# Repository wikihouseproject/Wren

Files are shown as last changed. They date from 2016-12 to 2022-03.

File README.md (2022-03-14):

### IMPORTANT: This is now an outdated, unsupported WikiHouse system. For the latest WikiHouse core system info please see the [Skylark repo](https://github.com/wikihouseproject/Skylark) and [WikiHouse guides](https://www.wikihouse.cc/guides)

# Wren

The language and rules for the Wren Wikihouse structural system, suitable for 1-3 storey buildings and initially developed in the UK for European contexts.

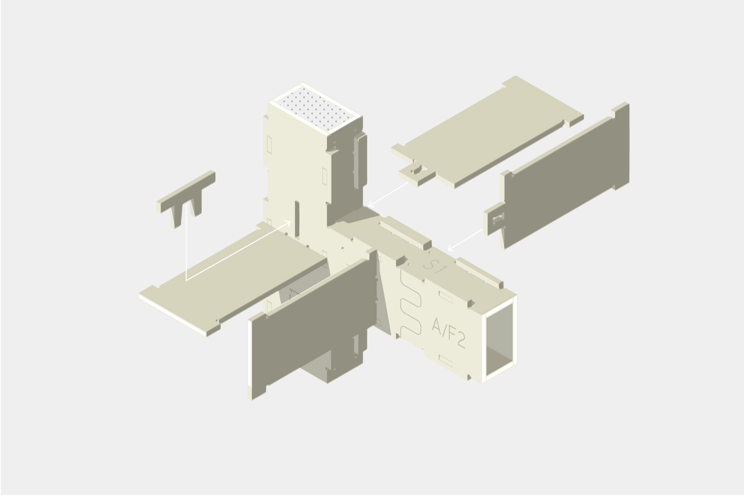
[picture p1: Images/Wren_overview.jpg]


## Wren Hardware

Wren components are CNC manufuctured using structural-grade timber panel materials (typically, plywood) and can be rapidly assembled to produce a structural chassis, onto which other components such as cladding, windows, doors can be fitted.

#### Wren is in development. For full documentation on how Wren works and how you can contribute to its development, visit the [Wren wiki](https://github.com/wikihouseproject/Wren/wiki)

## Wren Parametrics

This version of the Wren structural language has been developed in Grasshopper, the parametric scripting plugin for Rhino 3D. This computational design platform is widely used in the design and construction industries, and is ideally suited to digital manufacturing.

Other formats of the Wren system are currently being developed, but currently this version in Grasshopper format represents the latest thinking and workflow for the structural technology.

It should be taken as a Work in Progress and follows ‘a build something that works first’ approach. There are still several known areas where efficiency can be improved. There are also many ways the script can be extended to make use of Grasshopper’s expansive suite of tools include new features like structural analysis, nesting, GIS data, and solar/environmental tracking. We gladly welcome contributions from fellow computational designers to fork and develop!

### Licence

The repository Grasshopper file WikiHouse_WREN_(v4.3) has been developed by Architecture 00.  

It is licensed under Mozilla Public Licence (MPL) version 2.0. For full legal terms of this licence visit: https://www.mozilla.org/en-US/MPL/2.0/

### Plugins

This script makes use of the excellent developers toolbox of Grasshopper plugins, which makes this all possible. You will need to download and install the latest versions of these plugins from Food4Rhino.com before opening and running this script file.

The plugins used are:

- [Leafcutter](http://www.food4rhino.com/app/leafcutter-google-sheets-grasshopper) - for google sheets integration
- [Elefront](http://www.food4rhino.com/app/elefront) - for automated Grasshopper-to-Rhino flow
- [Human](http://www.food4rhino.com/app/human) - for automated Grasshopper-to-Rhino flow
- [Metahopper](http://www.grasshopper3d.com/group/metahopper) - for batch exports and script analysis

### Known issues / limits

- **D-Joint splitting of the frame** - there is currently a very basic version of the logic but this probably needs to be custom scripted. The basic rules are no section should be larger than the sheet material (nominally 1220 x 2440mm) and D-joints are never closer than two grips to any corner/junction
- **Integration with Google Sheets** - While you can ‘drive’ the Wren script using the parameter sliders, the best way makes use of the Leafcutter plugin, which connects the script with a google spreadsheet for the input and output of project data. This is particularly handy when setting out the window and door sizes and locations.
- **Number of roof points** - Here be bugs, it may not work for multiple roof points and may also break the frame/sheathing geometry. Use with care.
- **Tolerance** - While tolerances can be added to slots in the 3D model, a much better/safer approach is to add tolerance offsets to the final nested cutting files, and keep the 3D geometry at 0mm tolerance.
- **Data Tree structures** - These can be streamlined much further within the Sheathing and Spacer component clusters to improve the file size/solution speed
- Custom scripts - custom C# / Python scripts can and should be added to replace large sections of the script to improve the flow and speed up processing
- **End-walls (in development)** - The gable end walls use the Wikihouse Weaver system (cassette-based) and still more development needed on an automated workflow here, specifically with how the front and rear facades are divided up around window openings. The parametric script for Weaver is not yet included in this initial release.
- **Notes/comments** -  There’s a definite lack of these in the clusters and subclusters. More detail and comments will be added soon, my apologies! If you have particularly questions get in touch via email or raise an issue here.

## Wren Hardware R&D Contributions

**Architecture 00** (www.architecture00.net)
- [Alastair Parvin](https://twitter.com/AlastairParvin)
- [David Saxby](https://twitter.com/davidsx00)
- [Ryan McLoughlin](https://twitter.com/ryanjamesmac)
- [Clayton Prest](https://twitter.com/ClaytonPrest) 
- [Nick Ierodiaconou](https://twitter.com/nick_diaconou) 
- [Joni Steiner](https://twitter.com/jonisteiner)

**Momentum Engineering** (www.momentumengineering.com)
- Ben Whitfield
- Steve Fisher
- Rosie Stevenson

**Space Craft Systems** (www.spacecraft.co.nz)
- [Danny Squires](https://twitter.com/ecoarknz)
- [Martin Luff](https://twitter.com/martinluff)

**Arup Associates** (www.arup.com)
- Nina Tabink
- Adrian Campbell

**Individual Contributors**
- [Alex Whitcroft](https://twitter.com/AlexWhitcroft)
- Justyna Swat
- Nico Maes
- Akiko Kobayashi

**ULB Bruxelles**
- Structural engineering student group

## Wren Parametric Contributions

**Architecture 00** (www.architecture00.net)
- [Clayton Prest](https://twitter.com/ClaytonPrest) 

**Architype - Team Architects** (http://www.architype-ta.co.nz/)
- [Agneesh Brahmbhatt](https://www.linkedin.com/in/agneesh-brahmbhatt-7557234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)

If you believe you are missing from either of these lists of historical contributions, please contact us or fork this document to amend.

# Terms of use

By downloading these files or information you agree to the following terms and conditions.

Information is shared without any kind of warranty or guarantee
All Information is provided ‘as is’. No representations or warranties express or implied are made regarding the Wikihouse Info, its accuracy, completeness, functionality or fitness for a particular use in a particular location.  

You are solely responsible for the use of the information
By using this information you assume full responsibility for any loss resulting from use or inability to use the Wikihouse Info, and forever releases WikiHouse Foundation or other WikiHouse users from any liability for such loss;  including but not limited to loss of profits, goodwill or assets.

You are responsible for meeting local codes and legislation
Users must satisfy themselves regarding the application of statutory requirements, local building regulations, codes, insurance certification or other requirements or recommendations relevant to the location where and materials with which they plan to build. Where required you should always seek the advice of a relevant qualified professional.

You are responsible for using the information in a safe way
 Users are responsible for ensuring that information they use or cause to be used is used in a way which is safe, and is not likely to cause harm during or after manufacturing, construction, use or disassembly.

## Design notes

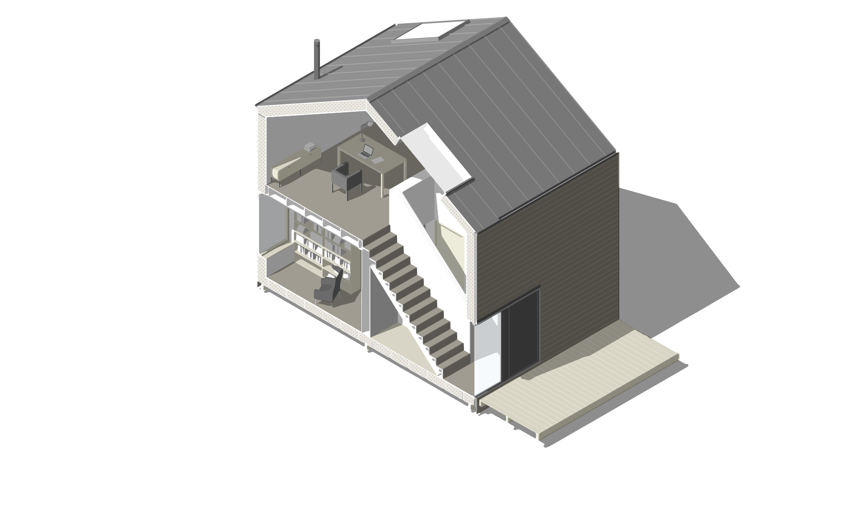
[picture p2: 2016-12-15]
Images/Process_8.jpg

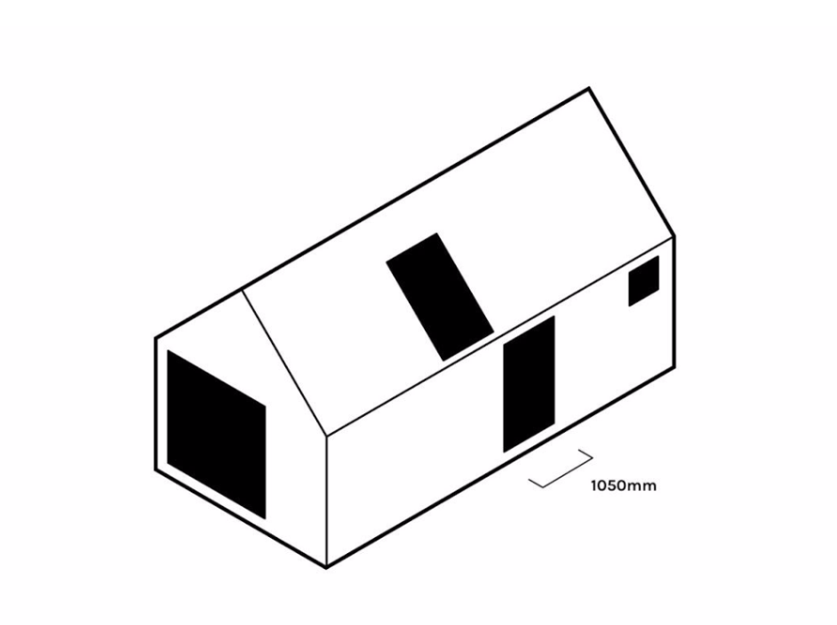
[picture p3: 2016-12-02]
Images/Openings-01.png

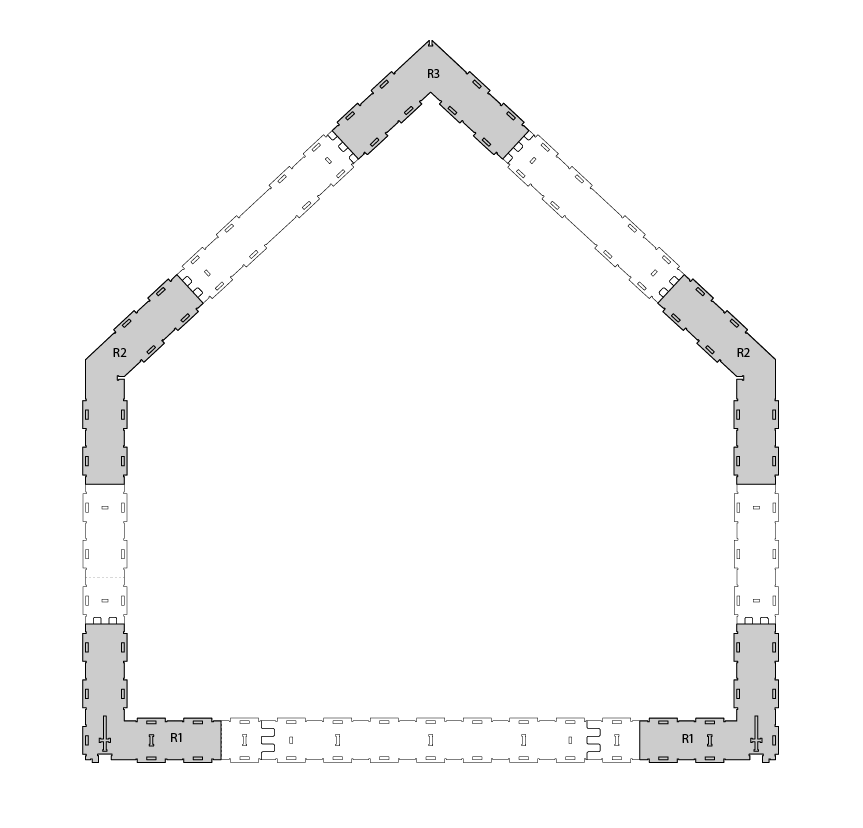
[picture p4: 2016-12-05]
Images/Reinforcer-01.png

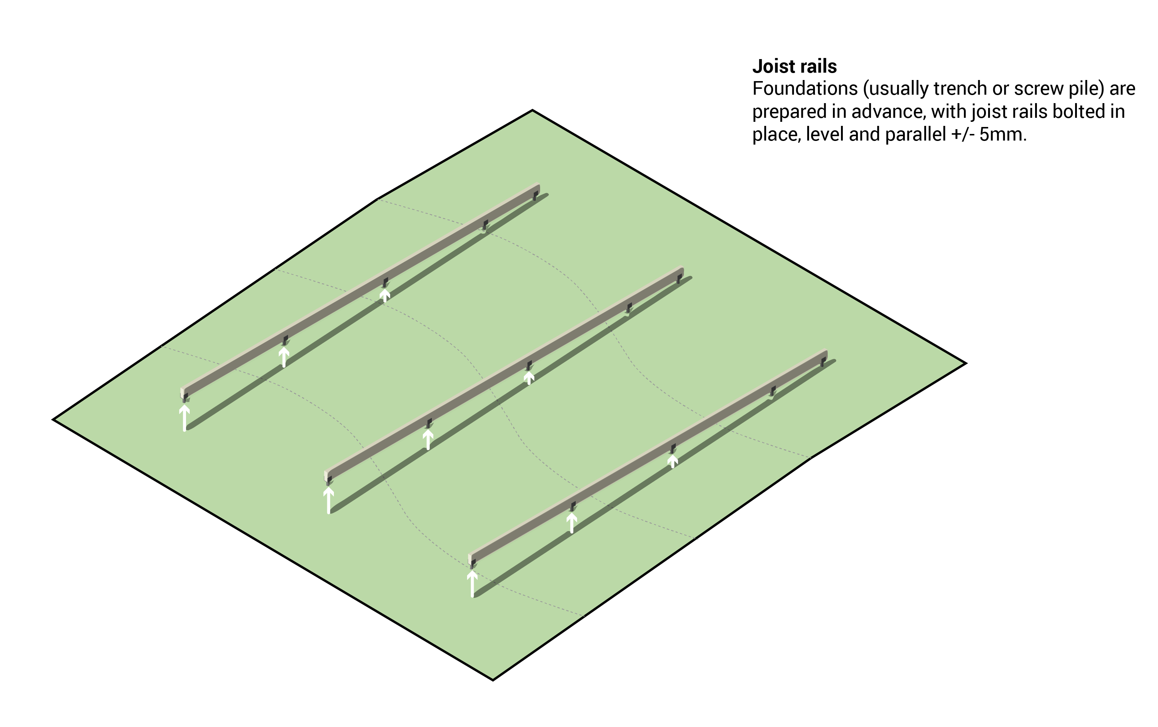
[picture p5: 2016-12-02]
Images/Foundation-01.png

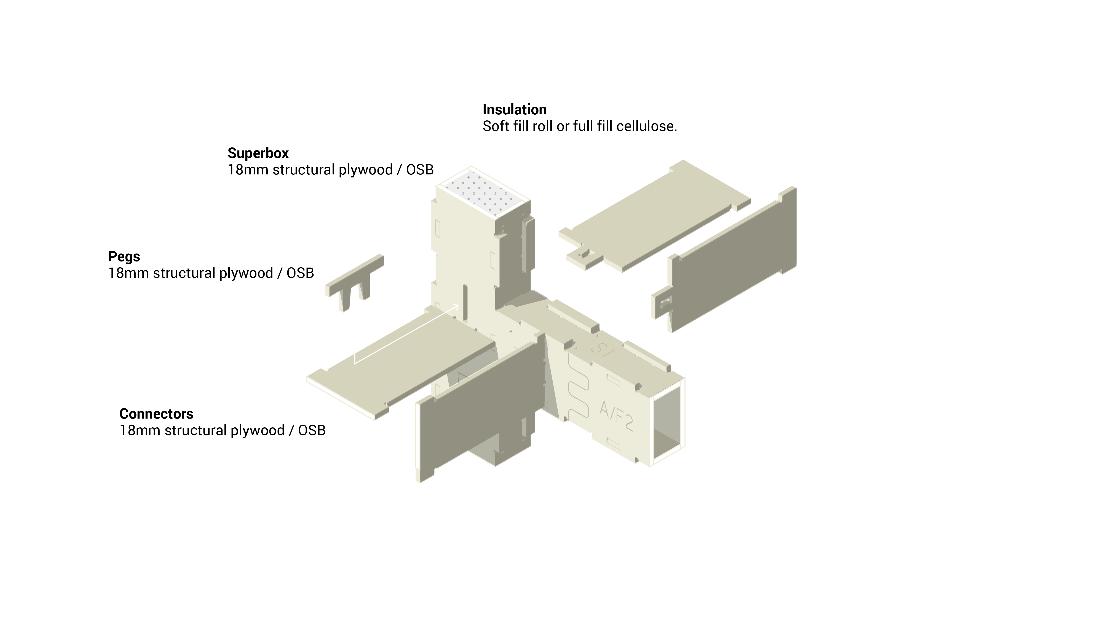
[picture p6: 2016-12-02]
Images/Connectors-01.png

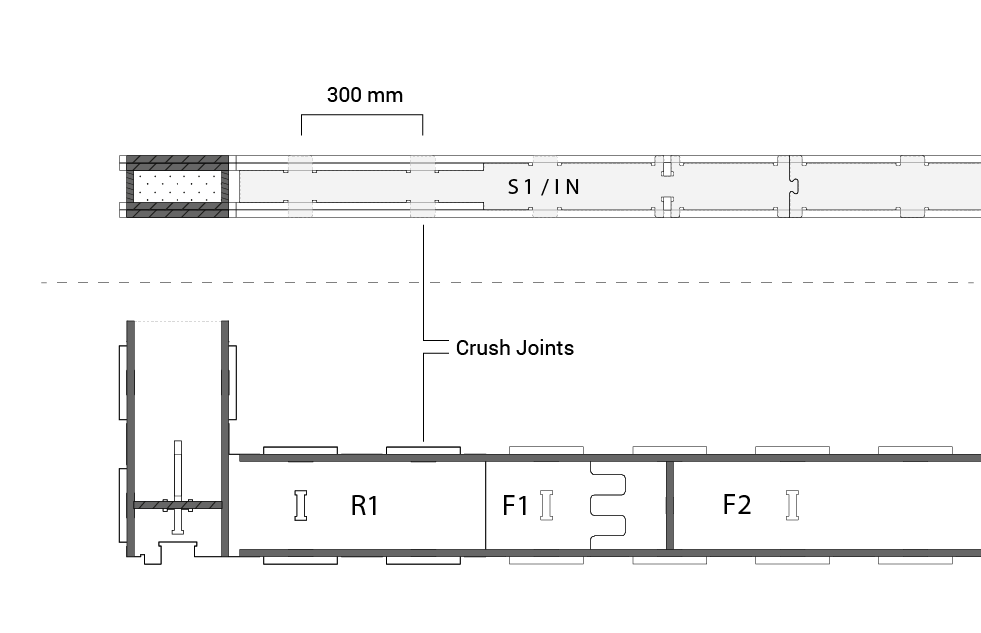
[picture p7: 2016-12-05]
Images/Spacers-01.png

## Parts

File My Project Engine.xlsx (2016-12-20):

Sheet: Dashboard
PLOT 1 | - | INPUT PARAMETERS |  |  | PLOT 1 | OUTPUT PARAMETERS
Building Dimensions | Centre-line Dimension | Units | Internal Dimension (mm) | External Dimension (mm) | Building Area | Value | Units
Width | 3900 | mm | 3553 | 4486 | Footprint Area | 34.32 | m2
Length | 7200 | mm | 7003 | 7650 | Ext Surface Area |  | m2
Height - Left Wall | 2400 | mm |  |  | Int Floor Area | 49.76 | m2
Height - Right Wall | 2400 | mm |  |  | Int Wall Area |  | m2
Height - Roof Apex | 3900 | mm |  |  | Int Roof Area |  | m2
Roof Apex offset | 0 | mm |  |  | Area of Openings | 14.66 | m2
Column Postion (From Left) | 0 | mm |  |  | End wall area |  | m2
1st Floor Height | 0 | mm |  |  | Thermal Analysis | Value | Units
 |  |  |  |  | Insulation Volume | 0.000 | m3
Building Form | Selection |  |  |  | Insulation Conductivity |  | m2K/W
roofPoints | 1 |  |  |  | Wall Thermal Conductivity |  | W/m2k
Column? | FALSE |  |  |  | Roof Thermal Conductivity |  | W/m2k
Two Storey? | FALSE |  |  |  | Internal Air Volume |  | m3
Mezzanine? | FALSE
 |  |  |  |  | Materials | Quantity (Total) | Units | Depth (mm) | Spec | Density (kg/m3) | Total Mass(kg)
Macro Parameters | Value (mm) |  |  |  | Plywood - Portal Frame |  | m3 | 18 | WISA Structural spruce ply | 510 | 0
Bays | 6 | bays |  |  | Plywood - Connecters/Sheathing |  | m3 | 18 | WISA Structural spruce ply | 510 | 0
Beam Width | 150 | mm |  |  | Plywood - End Walls |  | m3 | 18 | WISA Structural spruce ply | 510 | 0
Connector Grip Length | 80 | mm |  |  | Internal lining - Plasterboard | -49.763 | m2 | 9.5 |  |  | 0
Connector Slot length (Floor) | 80 | mm |  |  | Floor underside panels (http://www.wickes.co.uk/Wickes-Non-Structural-Hardwood-Plywood-5-5x1220x2440mm/p/110117) |  | m2 | 6 |  |  | 0
Connector Slot length (Wall) | 90 | mm |  |  | Wall Cladding |  | m2 |  |  |  | 0
Fin Depth | 250 | mm |  |  | Screws (http://www.wickes.co.uk/Wickes-External-Grade-Screws-Green-No-10x50mm-Pack-20/p/510124) |  | no. | 50 |  | 0.0058 | 0
Frame Grips length | 180 | mm |  |  | Insulation (Total External) (http://www.eksonser.com/cellulose.html) |  | m3 | 250 |  |  | 0
Gauge | 1200 | mm |  |  | Roof Cladding |  | m2 |  |  |  | 0
Ply Thickness | 18 | mm |  |  | External Membrane (http://www.dupont.co.uk/products-and-services/construction-materials/tyvek-building-envelope/brands/tyvek-breather-membrane/products/tyvek-uv-facade-rainscree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) |  | m2
Sheet Length | 2400 | mm |  |  | Internal Membrane (http://www.dupont.co.uk/products-and-services/construction-materials/tyvek-building-envelope/brands/airguard-vapour-control-layer/products/airguard-reflective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) |  | m2
Sheet Width | 1200 | mm |  |  | Vertical Battens |  | m
Spacing Ratio | 300 | mm |  |  | Horizontal Battens |  | m
Tolerance | 0 | mm |  |  | Guttering | 14.700 | m
Tool size (Dogbones) | 10 | mm |  |  | Downpipes | 4.800 | m
 |  |  |  |  |  |  |  |  |  |  | 0
External Cladding | Value (mm)
Cladding Thickness | 43 | mm |  |  | Estimates | Value | Units | Depth |  | Equation
Horizontal Batten Width | 32 | mm |  |  | No. of Chassis Plywood Sheets | 0 | Sheets | 18 | WISA Structural spruce ply | APPROX ONLY
Vertical Batten Width | 75 | mm |  |  | Volume - Single Plywood Sheet | 0.0535824 | m3
 |  |  |  |  | Average CNC Waste Factor | 0.30
Internal Lining | Value (mm)
Plasterboard Thickness | 9.5 | mm |  |  | Estimated Cutting Time | 0 | minutes |  |  | Time/sheet x sheets
Batten Width | 34 | mm |  |  | People Required / Single Frame | 0 | Humans |  |  | 25kg / person
Batten Height | 21 | mm |  |  | Misc items | Value | Units
 |  |  |  |  | Sink |  | Kg
Stair Parameters | Value (mm) |  |  |  | Gutter and rainwater pipes |  | Kg
Stair Length |  | mm |  |  | Instant boiler |  | Kg
Tread/Going Length |  | mm
Riser Height |  | mm
Cladding Material | Material
North Elevation
East Elevation
South Elevation
West Elevation

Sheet: WindowDoor
PLOT 1 | WINDOW, ROOF LIGHT & DOOR SCHEDULE
LOCATION - Front = Entrance Door | WINDOW / DOOR | Bay Location | Level | Side - A(left) / B(Right) / C(UpperLeft) / D(UpperRight) | Opening width (+/- 5mm) | Opening height (+/- 5mm) | Unit width (mm) | Unit height (mm) | Height from junction centreline | Distance from left | Height from floor | Perimeter length | Opening Area (m2) | Width to packer | Spec | Link | Price (Ex VAT)
East Elevation (End wall) | WN-01 | RW | GF | A | 2118 | 2118 | 2113 | 2113 | 0 | 0 |  | 8452 | 4.485924 |  | Fixed
North Elevation (Front)
North Roof | RL-01 | 02 | RF | A | 1050 | 1695 | 1045 | 1690 | 228.8 | - |  | 5470 | 1.77975 |  | Fixed
 | RL-02 | 05 | RF | A | 1050 | 1695 | 1045 | 1690 | 228.8 | - |  | 5470 | 1.77975 |  | Fixed
South Elevation (Rear) | DR-01 | 04 | GF | B | 1050 | 2100 | 1045 | 2095 | 125 | - |  | 6280 | 2.205 |  | Opener
 | WN--02 | 03 | GF | B | 1050 | 2100 | 1045 | 2095 | 125 | - |  | 6280 | 2.205 |  | Fixed
South Roof
West Elevation | WN-03 | FW | GF | A | 2118 | 2118 | 2113 | 2113 | 0 | 0 |  | 8452 | 4.485924 |  | Fixed
 |  |  |  |  |  |  |  |  |  |  |  | WINDOW AREA (m2): | 12.46
 |  |  |  |  |  |  |  |  |  |  |  | DOOR AREA (m2): | 2.21

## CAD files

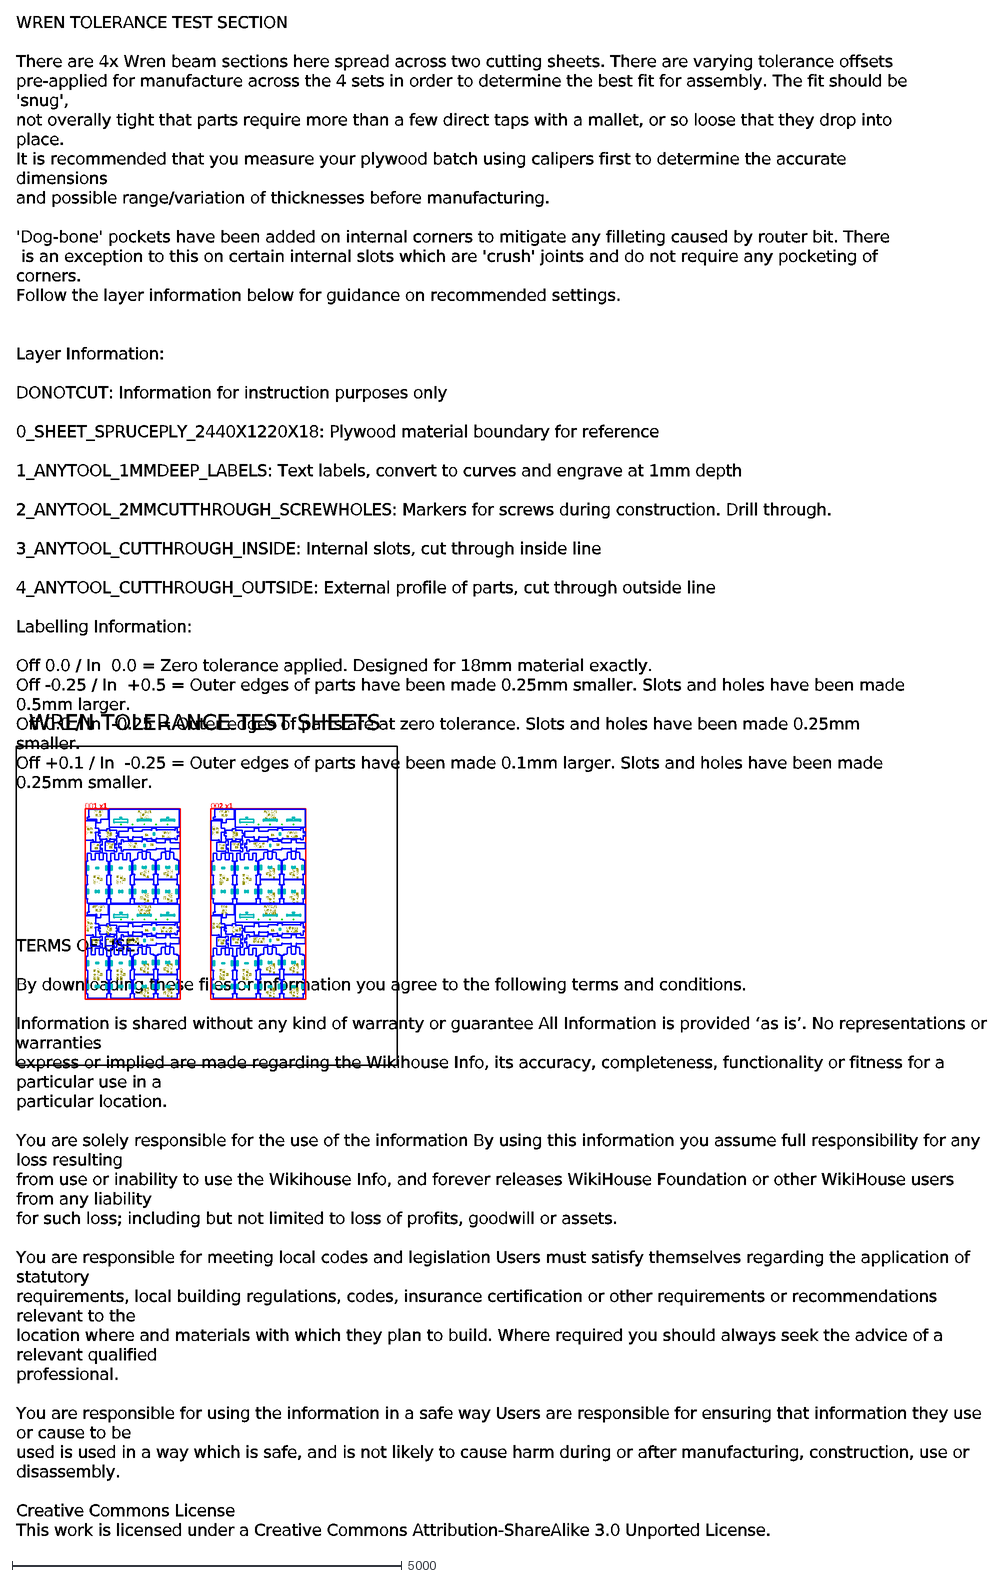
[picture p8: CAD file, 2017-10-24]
Assembly Test/Wren_Tolerance-Test_CNC-cutting_v1.dxf
FLOOR / 1 Off 0.0 In 0.0
TERMS OF USE: By downloading these files or information you agree to the following terms and conditions. Information is shared without any kind of warranty or g
WREN TOLERANCE TEST SECTION There are 4x Wren beam sections here spread across two cutting sheets. There are varying tolerance offsets pre-applied for manufactu
Off +0.1 In -0.25
Off 0.0 In -0.25
Off -0.25 In +0.5
Off 0.0 In 0.0
F2 Off +0.1 In -0.25
R1 Off +0.1 In -0.25
F1 Off +0.1 In -0.25
F2 Off 0.0 In -0.25
SI1 Off +0.1
S2 Off 0.1
CON Off +0.1
WREN TOLERANCE TEST SHEETS
002 x1
001 x1
F1 Off 0.0 In -0.25
R1 Off 0.0 In -0.25
S1
CON Off 0.0
SI1 Off 0.0
S2 Off 0.0
S2 Off -0.25
F1 Off -0.25 In +0.5
R1 Off -0.25 In +0.5
F2 Off -0.25 In +0.5
SI1 Off -0.25
CON Off -0.25
R1 Off 0.0 In 0.0
F2 Off 0.0 In 0.0
F1 Off 0.0 In 0.0
FLOOR / 1 Off -0.25 In +0.5
FLOOR / 1 Off 0.0 In -0.25
FLOOR / 1 Off +0.1 In -0.25

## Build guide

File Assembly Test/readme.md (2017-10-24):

# Wren Assembly Test

A small prototype component of the WREN system to test assembly and machining tolerances with.

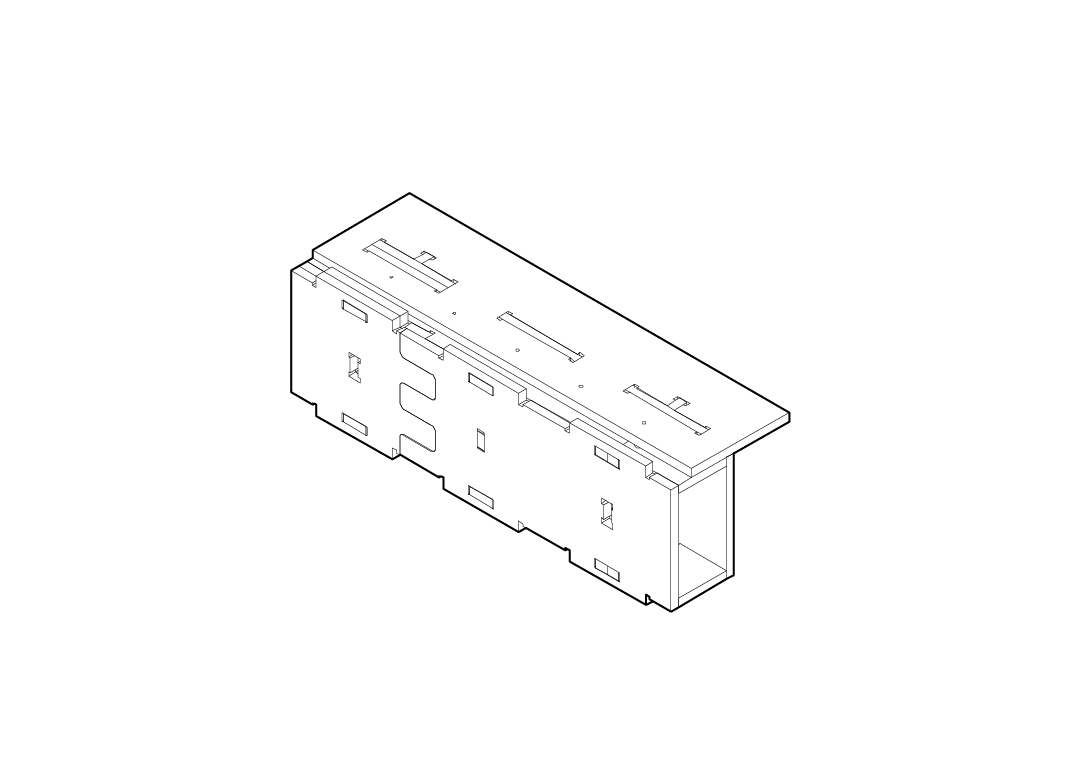
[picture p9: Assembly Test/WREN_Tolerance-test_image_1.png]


## Wren Hardware

Wren components are CNC manufuctured using structural-grade timber panel materials (typically, plywood) and can be rapidly assembled to produce a structural chassis.

#### Wren is in development. For full documentation on how Wren works and how you can contribute to its development, visit the [Wren wiki](https://github.com/wikihouseproject/Wren/wiki)

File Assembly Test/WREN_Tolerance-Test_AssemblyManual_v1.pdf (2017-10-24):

# WREN ASSEMBLY

# CNC Manufacturing Sample

2017

## Wren Assembly Test

UK

v1.0 | 10/2017 | WikiHouse Foundation

### Estimated assembly time 0.2 Hours Difficulty level 1

# TEST

# IMPORTANT

# By using this information you agree to

the following terms and conditions.

## Information is shared without any kind of warranty or guarantee All Information is provided ‘as is’. No representations or warranties express or implied are made regarding

the Wikihouse Info, its accuracy, completeness,

## functionality or fitness for a particular use in a particular location. Please note WikiHouse building technologies are in a ‘beta’ mode, which means they

are still in development.

You are solely responsible for the use of the information By using this information you assume full responsibility for any loss resulting from use or inability to use the Wikihouse Info, and forever releases WikiHouse Foundation or other WikiHouse users from any liability for such loss; including but not

limited to loss of profits, goodwill or assets.

You are responsible for meeting local codes and legislation Users must satisfy themselves regarding the application of statutory requirements, local building regulations, codes, insurance certification or other requirements or recommendations relevant to the location where and materials with which they plan to build. Where appropriate you should always seek the

advice of a relevant qualified professional.

## You are responsible for using the information in a safe way Users are responsible for ensuring that information they use or cause to be used is used in a way which is safe, and is not likely to cause harm during or after

manufacturing, construction, use or disassembly.

## Personal protective equipment (PPE)

All construction is dangerous. Always wear hard hards, eye protection, ear protection (malleting gets very loud), gloves, high visibility outfits and steel-capped boots. Where working at height is required, use a harness. Establish a ‘safety first’ culture on site, and encourage the continuous identification of hazards.

## Difficulty level 2

Most of this assembly can be safely performed by a small team of any able-bodied people without formal construction skills.

Other services, such as electrical installations and structural / building regulations certification can only be done or approved by a certified professionals. Consult a professional if you are unsure.

## Working at height

This assembly requires a limited amount of working at height to complete the roof. Do a risk assessment, and use appropriate stepladder and / or scaffolding as well as Step Ups to minimise the risk of falling. If in doubt, refer to www.hse.gov.uk

## First Aid

Before commencing, check there is a First Aid kit and appropriate Fire Extinguisher on site, and if possible, identify a qualified first-aider. Make sure you record important contact and medical information from everyone on site.

## Site preparation

Make sure passers-by can’t wander onto your site. It’s also a good idea to warn neighbours in advance that there’ll be some noise, especially from malleting.

## Tools

For this assembly you will need:

1+ Mallets
1+ Electric screwdrivers with as many spare batteries as possible 1x Electric drill
1x Vernier Callipers
1x hand screw driver (to use as a lever)
2 x Large clamps

1

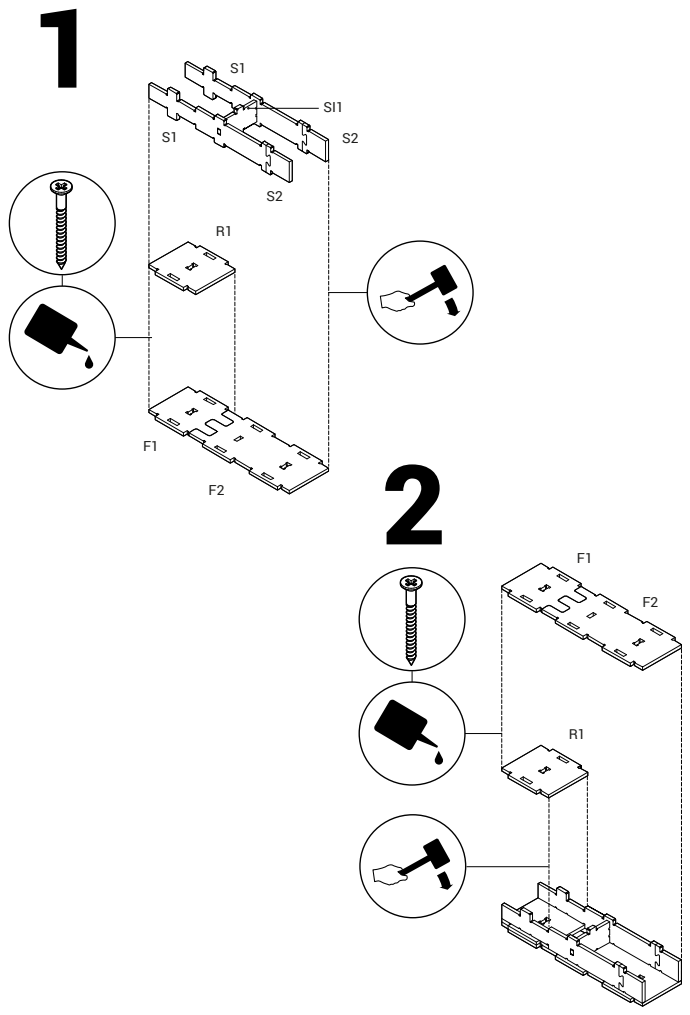
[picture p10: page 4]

## WREN Assembly Test

v1.0 | Date | Your name

Please scan all your site notes from the process and compile them into a single document. Please upload them to your project folder or email them to

clayton@wikihouse.cc

CNC Manufacturing Sample | 1

Feedback / design modification suggestions

3

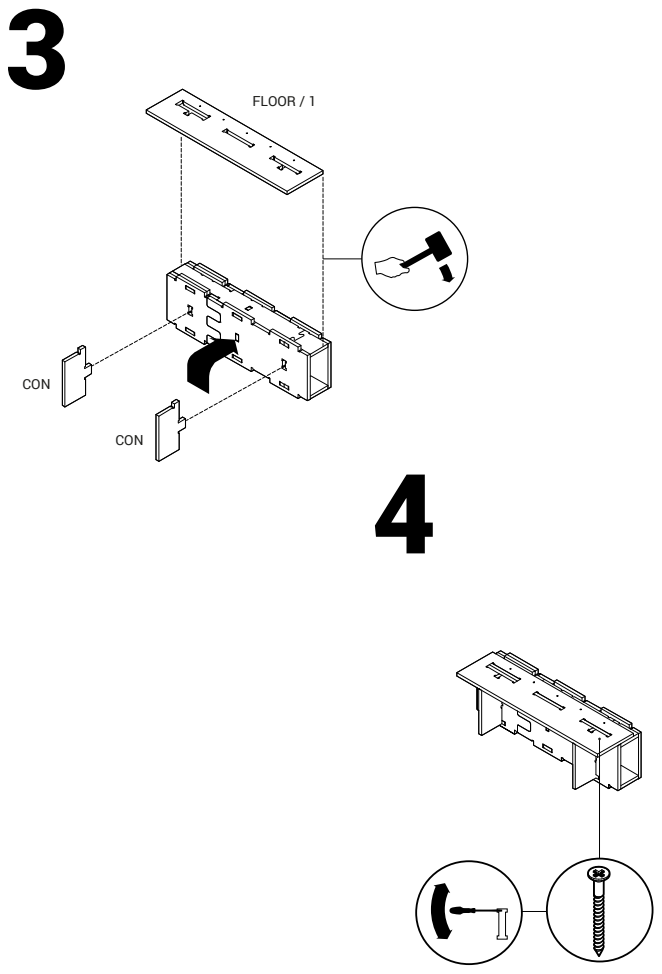
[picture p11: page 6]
CON; FLOOR / 1

## WREN Assembly Test

v1.0 | Date | Your name

Please scan all your site notes from the process and compile them into a single document. Please upload them to your project folder or email them to

clayton@wikihouse.cc

CNC Manufacturing Sample | 2

Feedback / design modification suggestions

5

a | b

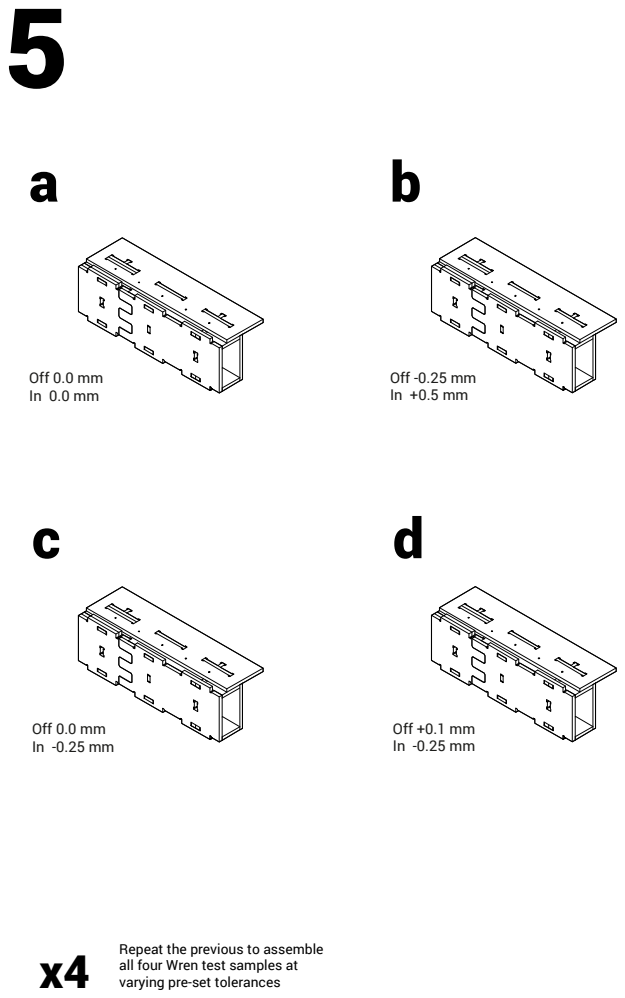
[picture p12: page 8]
Off 0.0 mm In 0.0 mm; Off -0.25 mm In +0.5 mm; Off 0.0 mm In -0.25 mm; Off +0.1 mm In -0.25 mm

x4 Repeat the previous to assemble

all four Wren test samples at
varying pre-set tolerances

## WREN Assembly Test

v1.0 | Date | Your name

Please scan all your site notes from the process and compile them into a single document. Please upload them to your project folder or email them to

clayton@wikihouse.cc

CNC Manufacturing Sample | 3

Feedback / design modification suggestions

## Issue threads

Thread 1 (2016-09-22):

Wren system timeline

lvivier, 2016-09-22:
@claytonprest can you give any indication of when we might see the Wren system files in this repo? If there's anything I can do to help, I'm volunteering, though my CAD skills be rusty.

claytonprest, 2016-09-22:
@lvivier Hi Luke, we're currently preparing the parametric Wren files for release, and road-testing it on a size-able pilot project in London. I expect within the next 2 months we'll have them hosted up on here. Initially these will be Rhino/Grasshopper (.ghx/.xml) format, but we are developing a parallel javascript code for the Wren system which will be much more accessible to developers.

In the meantime, the most up-to-date reference for Wren is the chassis model in the Microhouse repo, along with the accompanying assembly guide.

lvivier, 2016-09-22:
Thanks for the quick response, @claytonprest. I'm excited to see the parametric files and especially the code. JavaScript is my day job so I can probably help out more when that comes to light.

Not really pertinent to the issue, but is there a Slack or other chat channel where WikiHousers are connecting day to day?

claytonprest, 2016-09-23:
@lvivier  Yes indeed - we have a Wikihouse community Slack. What's your email? I'll get an invite sent out to you.

cleberfigueiredo, 2016-09-23:
hey, @claytonprest - would you be able to send me an invite also? it seems my old invite to slack is not working anymore. I'm running the Canadian chapter and need to keep up to date on what is happening.

lvivier, 2016-09-23:
@claytonprest I'm luke@vivier.ca

Closed 2016-10-12.

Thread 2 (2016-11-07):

Test pull-out loads of screws fixed into end grain of plywood

claytonprest, 2016-11-07:
There is currently no data for the loading limits of screws fixed into end grain of plywood. This limits the possible connection points in the Wikihouse system and creating additional joinery is costly in additional materials and fabrication time. If we can determine that the end-grain screw loads are comparable to the face-fixed screw loads it will cut down materials and allow more flaxibility for design, particularly with cassette systems like Wren's end walls.

What we need help with:
- [ ]  Design a pull-out test to determine maximum structural loads
- [ ]  Carry out designed test using a loading rig and several sheet materials options beginning with 18mm WISA structural spruce plywood.
- [ ]  Document the testing process, collate data, and share back with project community

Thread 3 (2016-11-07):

Wind Exposure limitations - Test Racking loads of Wren chassis

claytonprest, 2016-11-07:
Racking testing is a vital structural requirement for Wren, as the design of timber structures is usually governed by stiffness rather than strength as the structure reaches the serviceability limit state (SLS) before the ultimate limit state (ULS). The racking performance of the Wren chassis needs to be measured in accordance with Eurocode 5 and relevant test standards.

This will likely require a laboratory based investigation was developed and executed to determine the racking resistance of the Wren sheathing components in y-axis for both a typical 2 storey and 1 storey Wren chassis in a range of UK wind exposure limits.

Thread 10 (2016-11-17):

Zips - testing the dovetailed joint between two sheathing panels

claytonprest, 2016-11-17:
Zips - testing the dovetailed joint between two panels of sheathing to determine localised failure mechanism and overall tension capacity

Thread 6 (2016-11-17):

Holes - testing the effect of a hole in a rib

claytonprest, 2016-11-17:
Holes - testing the effect of a hole in a rib, in terms of strength and stiffness

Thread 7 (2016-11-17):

Grips - testing the failure mechanisms of single rib grip slotted into a spacer

claytonprest, 2016-11-17:
Grips - testing to establish the localised failure mechanisms of single rib grip slotted into a spacer

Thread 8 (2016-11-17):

D-joints - testing the failure mechanisms of a rib dovetail joint subjected to shear force

claytonprest, 2016-11-17:
D-joints - testing a rib to establish the localised failure mechanisms of the dovetail subjected to shear force

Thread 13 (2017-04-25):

first-time-friendly

HarryKnight, 2017-04-25:
If you're new to Github and have never improved code or documentation here before, it can be a bit confusing. If this is you, you've come to the right place. Just leave a comment in here to ask any questions and tag @claytonprest, myself, or @johnrees . We can help you make an improvement to this documentation.

Hydrom99, 2017-07-27:
@claytonprest  Hello I am a volunteer at FabLab in New Zealand (Masterton) and we are going to attempt to make a tiny house  on the order of 3Mx3M and i am looking for files that might help to that end  this site is quite exciting but also a bit confusing could you possibly point me in the right direction
Thanks kindly Dennis
Cheers

claytonprest, 2017-07-31:
@Hydrom99 Hello! Thanks for getting in touch, it's always great to hear from people in NZ doing exciting things.

The best place to start is by downloading all the Microhouse design files from [the repo here](https://github.com/wikihouseproject/Microhouse).  This is a example design using the latest iteration of the Wikihouse Wren construction system, and a good template for creating your own custom design using Sketchup or other CAD software. There's

pnprince, 2018-04-17:
@claytonprest I am trying to custom design mini house and would like to play with WREN in grasshopper.So far I have downloaded Rhino 6 and listed plugins with no success. I am having issues with version mismatch. Is there a list available somewhere for all compatible versions? I am interested in using Parametric side of WREN. Thank you.

LeslieIng, 2019-03-20:
@claytonprest @HarryKnight @johnrees  @pnprince Hello! I too am interested in getting the parametric side working on Rhino 6. The plugin leafcutter appears to be discontined, so I wonder how I should continue.
Cheers

kosmasg, 2019-10-16:
**@claytonprest** I am pursuing a PhD in the field of Digital Open Design Commons and i want to contribute at WREN known or other issues\limits as part of my research agenda. I have a working knowledge of Rhino, GH, RVB and RhinoPython. Please let me know the working version of GH plugins (Human is currently available only in Rhino 6 and leafcutter is discontiniued). Could you provide the gha files of the plugins in use?

kosmasg, 2019-10-25:
@claytonprest  @HarryKnight  @johnrees Regarding my previous comment/request I have found the required plugin versions to run WREN grasshopper file in rhino 5 in secondary sources. I wonder whether the open issues mentioned at readme file (open issues/limits) are still open or the only currently open tasks are those mentioned under github issues section. Could you please clarify?

Furthermore, I can not recognize any input for door or window placement in GH inputs or pilot engine database. Am I missing something?

For other contributors it seems that these plugin versions work for Rhino 5:
[Human](https://www.grasshopper3d.com/group/human/forum/attachment/download?id=2985220%3AUploadedFile%3A1435682)
[Leafcutter](https://github.com/fluxio/leafcutter/tree/master/Installer%20Package/LeafcutterInstall)
Cheers

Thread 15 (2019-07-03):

Rhino 6 Compatibility issues

mayafox, 2019-07-03:
attempting to import the Wren grasshopper files into Rhino 6 causes unrecognized object errors for Elefront and Human.

timmythomas, 2019-08-15:
The WREN GH file wants Elefront version 0.1.0.0. The current version is 4.2.
The WREN GH file wants Google Drive for GH (Leafcutter?) version beta 1. No plug-in found.
I am not sure if these are easy fixes. Please, advise.  Thanks.

pfmephisto, 2020-04-15:
@timmythomas
Leafcutter can still be found on [GitHub](https://github.com/fluxio/leafcutter)
That said, it dosen't work with Google Sheets anymore.

Therefore I want to see if I can change the script to function with. A regular excel file first.
Does anyone still have the original Google Sheets File so I could use it as a template?

kiskovce, 2020-04-24:
Hi @pfmephisto ,

can You give us little more info what is/ how to use Leafcutter to avoid EleFront issue in Rhino 6. , please?

*can be EleFront 0.1.00 "ElefrontProperties.rhp" found here in community?

pfmephisto, 2020-04-24:
Hi @kiskovce,

I'm not sure which issue with Elefront you are having, but if I remember correctly I'm using the latest version from [Food4Rhino](https://www.food4rhino.com/app/elefront).
But I can check for you net time I'm at my PC.

As far as other issues. When I open the file it's far from perfect. I have one Cluster that has a strange exclamation mark that I have not seen other wise before. Some connections seem to be missing and there are some issues with the list order inside some components.

But honestly I've just started meticulously going through each cluster and understanding what it does.

kiskovce, 2020-04-25:
Hi @pfmephisto ,

thank you for your reply and interest.
my Wren - Rhino 6 issue:

I tried to open  _WikiHouse_WREN_(v4.3).gh_ in Rhino but it can't open because  "Unrecognize Object "

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

So I fond elefront at https://www.food4rhino.com/app/elefront and downlead it manually  and install according readme.txt.

But I can't still open _WikiHouse_WREN_(v4.3).gh_ because Unrecognize Object EleFront.

Can be this solve by update _WikiHouse_WREN_(v4.3).gh_ with newer version of elefront?

Thank you for your support.
MK

melhof, 2020-08-05:
Still here experiencing all the above issuess now over a year later.
How do we cry for help, so that the WikiHouse developers will listen and (help to) solve this problem?
@claytonprest @Alastairparvin

pfmephisto, 2020-08-16:
@melhof If you are able and willing to tinker around with the script, I have started reworking some of it in my fork of the project inside the development branch. It's far from solved and still does not fully support all the origin functionality. But it is good enough for the project we had planed. Sadly that project got sidelined for now due to COVID-19 and I'm not sure when I'll get back to working on the wikiHouse.
But I'll try to make some time next week to clean up the branch and push my latest changes.

In terms of getting help form the wikiHouse developers. From my limited insight is seems they have moved on and are developing a new system they call blackbird, which as of now is still in beta. This means that, they have a guide for the new system, but development of an automatic configurator has not been finished yet.
Also it seems that they are moving away fron grasshopper in favour of a web based solution.

In my opinion, if there is still a wish to use the Wren system even in the light that in a couple of years there might be a new version. Then an effort should be made to rewrite it from the ground up and simplify it along the way. As the way it is now it runs quite slowly an in written very confusingly.

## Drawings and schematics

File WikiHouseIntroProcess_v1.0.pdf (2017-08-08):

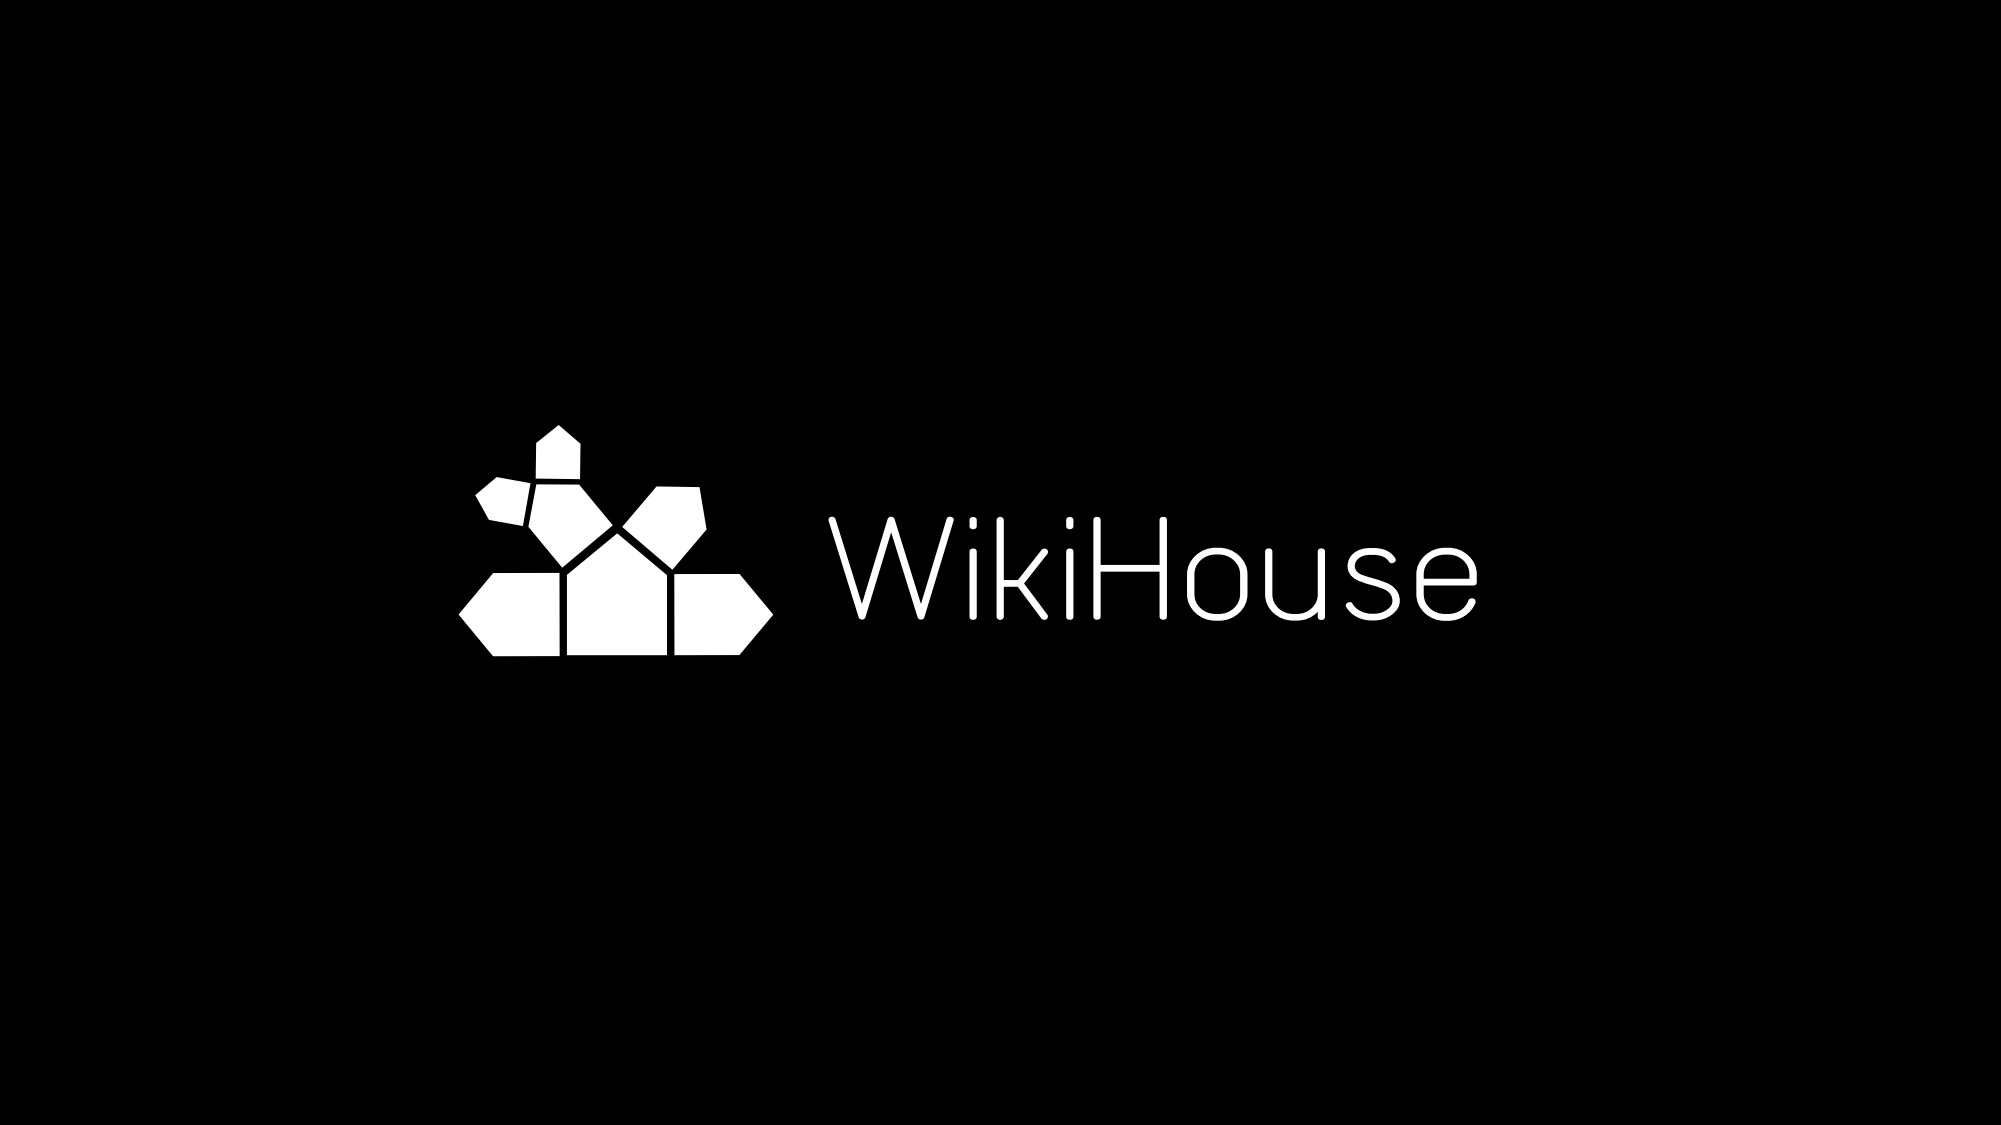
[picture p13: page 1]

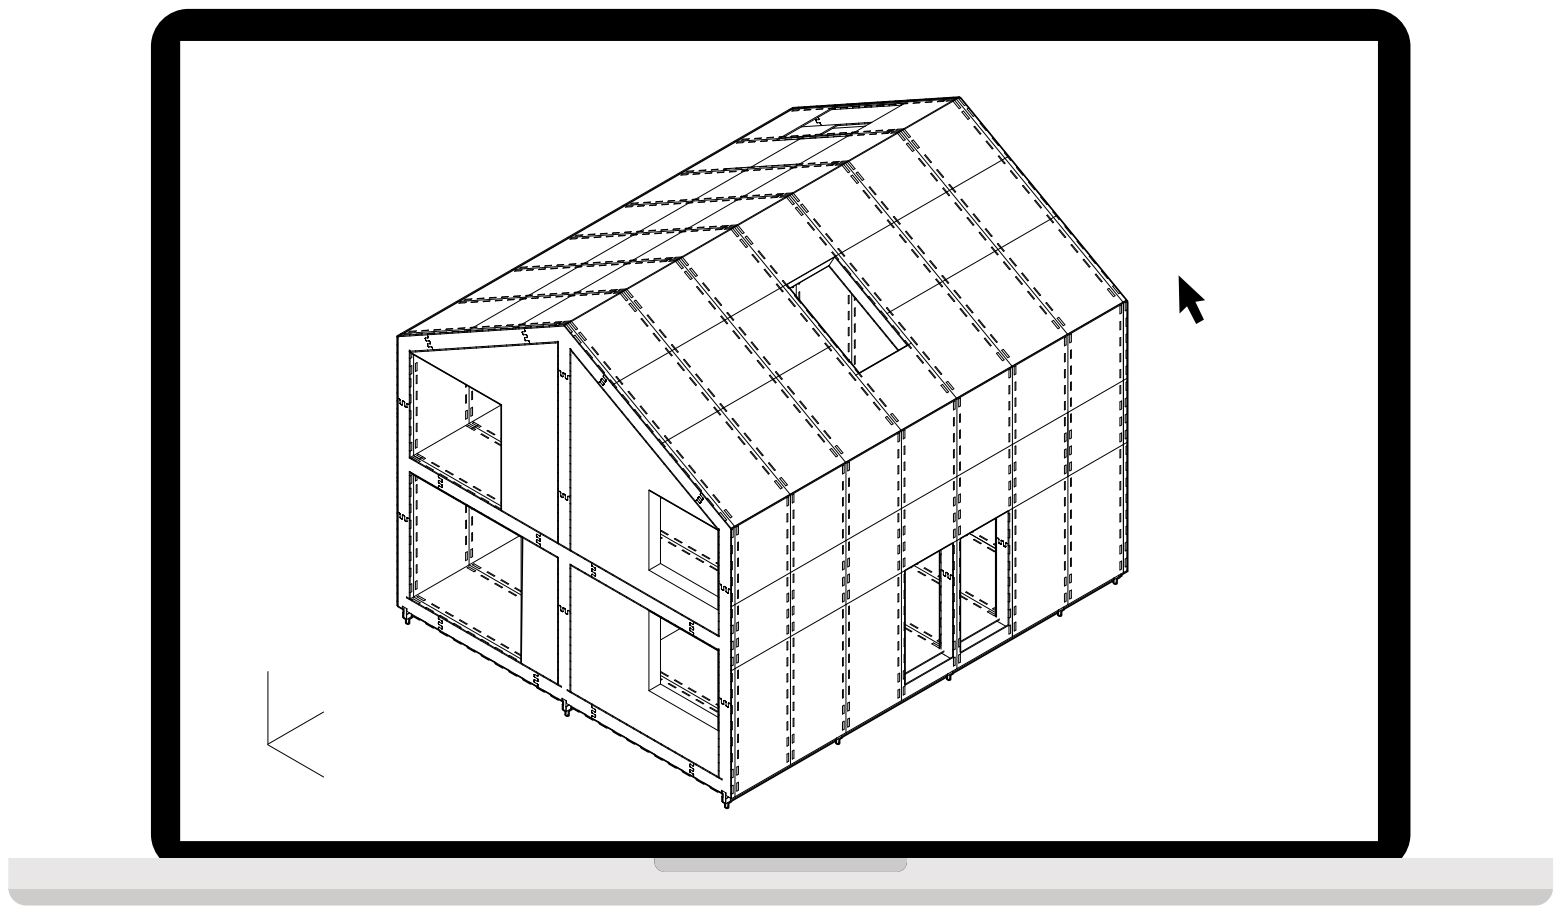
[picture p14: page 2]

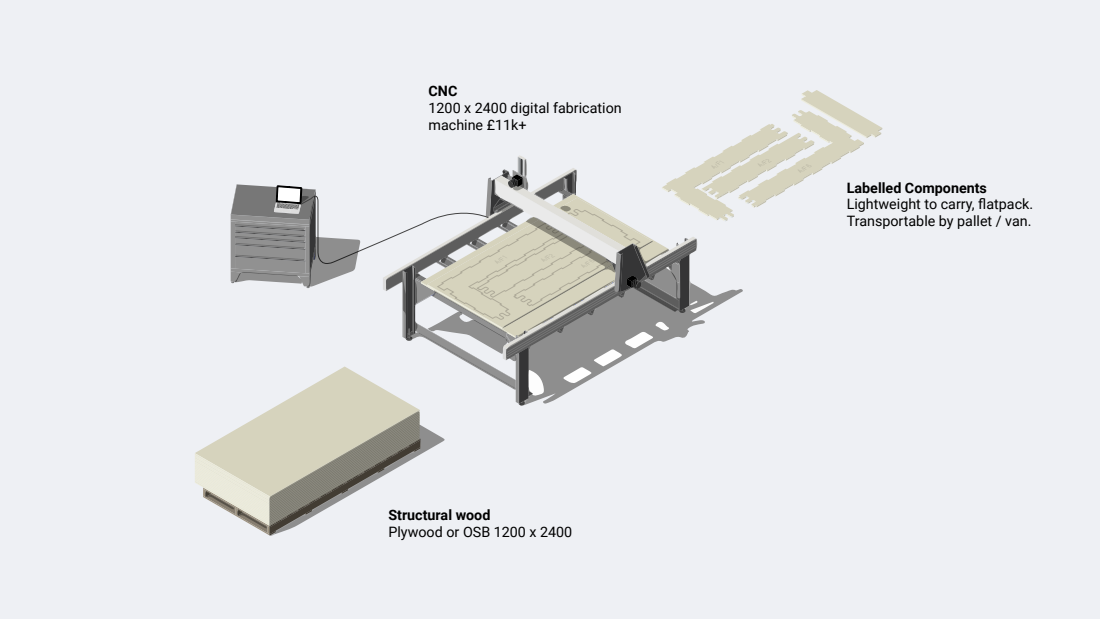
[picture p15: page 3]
CNC 1200 x 2400 digital fabrication machine £11k+

Labelled Components
Lightweight to carry, flatpack.
Transportable by pallet / van.

Structural wood
Plywood or OSB 1200 x 2400

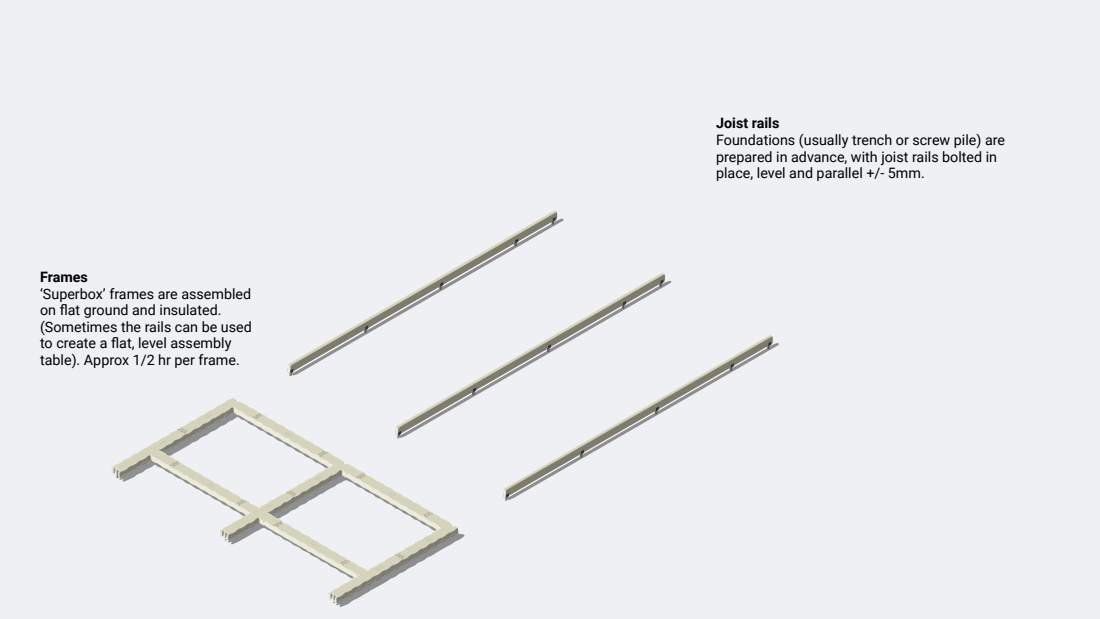
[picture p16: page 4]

Joist rails
Foundations (usually trench or screw pile) are
prepared in advance, with joist rails bolted in
place, level and parallel +/- 5mm.

Frames
‘Superbox’ frames are assembled
on flat ground and insulated.
(Sometimes the rails can be used
to create a flat, level assembly
table). Approx 1/2 hr per frame.

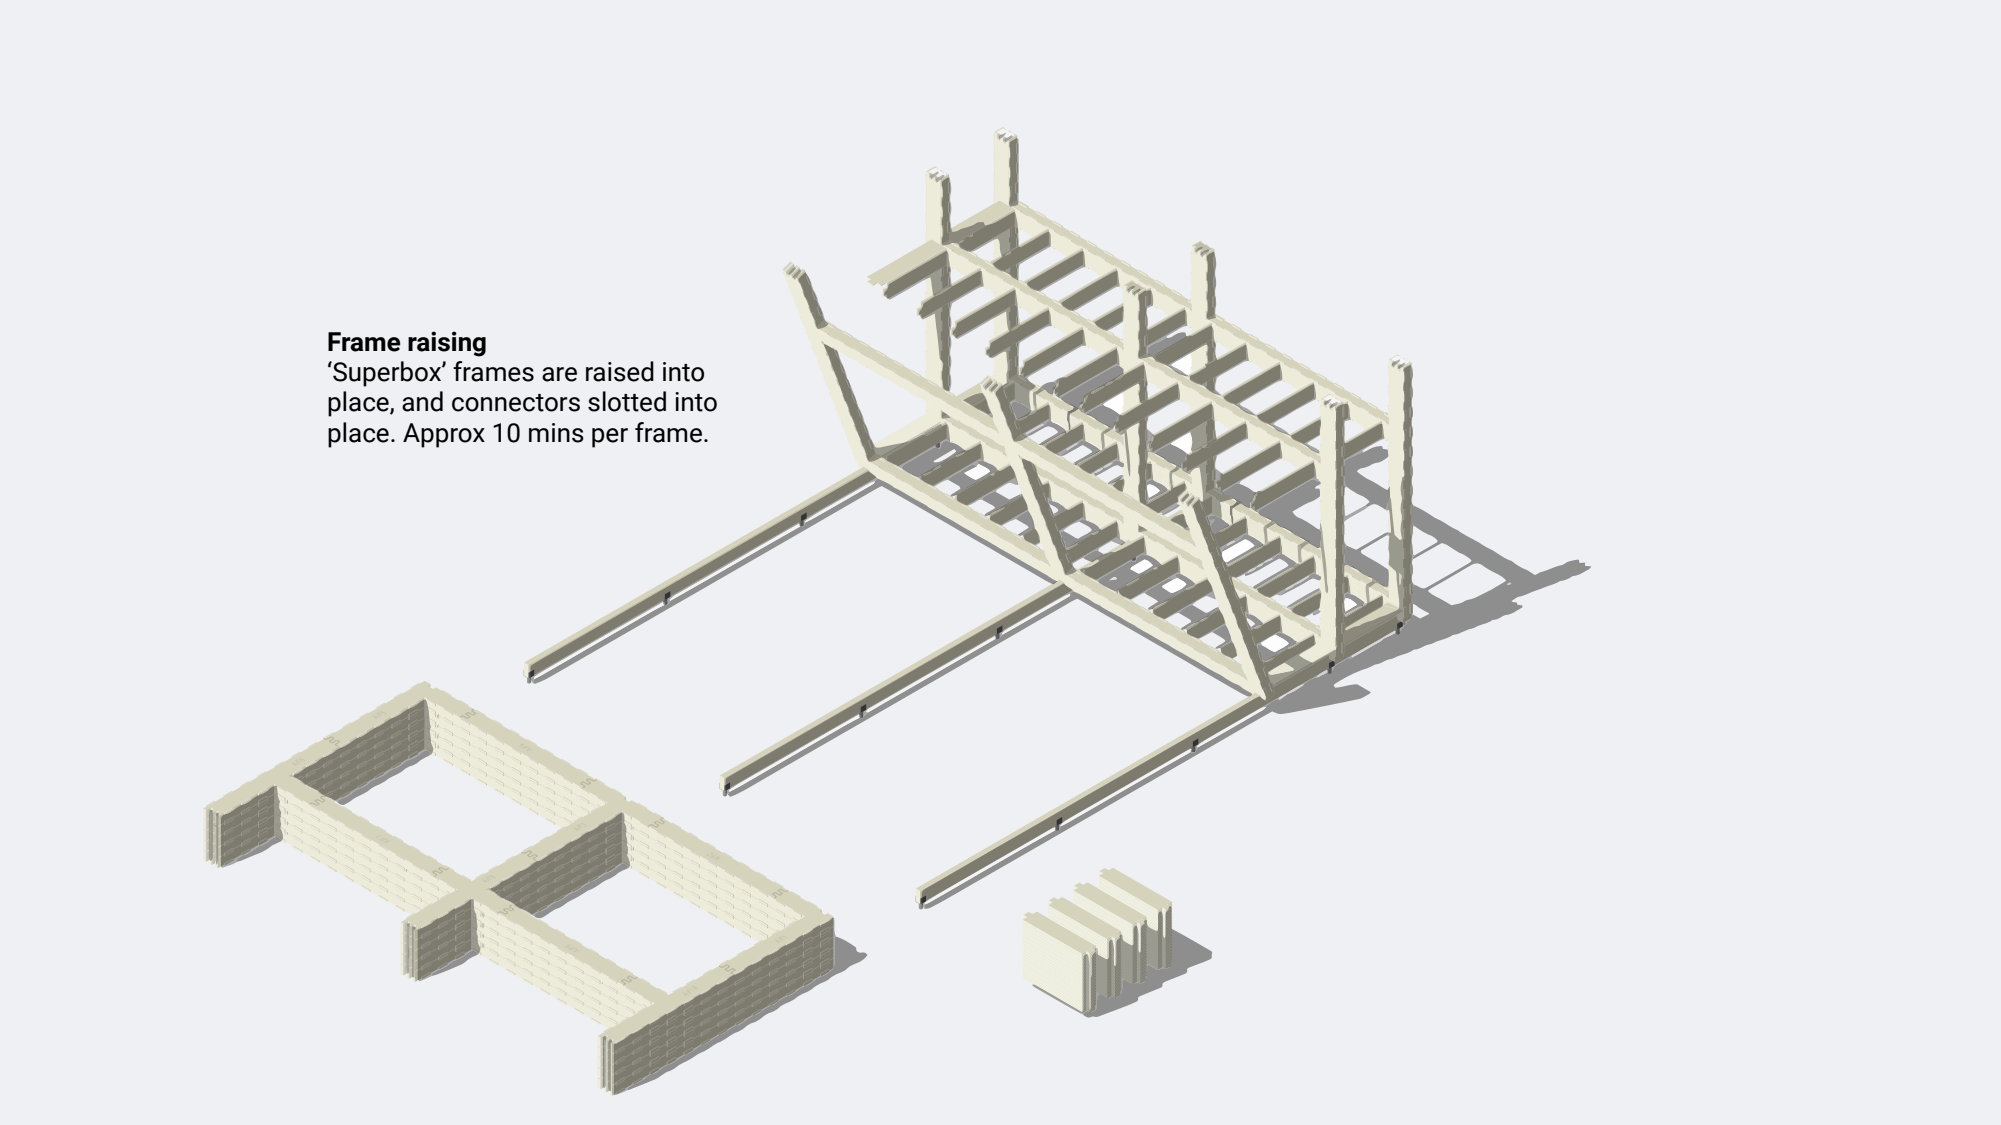
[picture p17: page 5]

Frame raising
‘Superbox’ frames are raised into
place, and connectors slotted into
place. Approx 10 mins per frame.

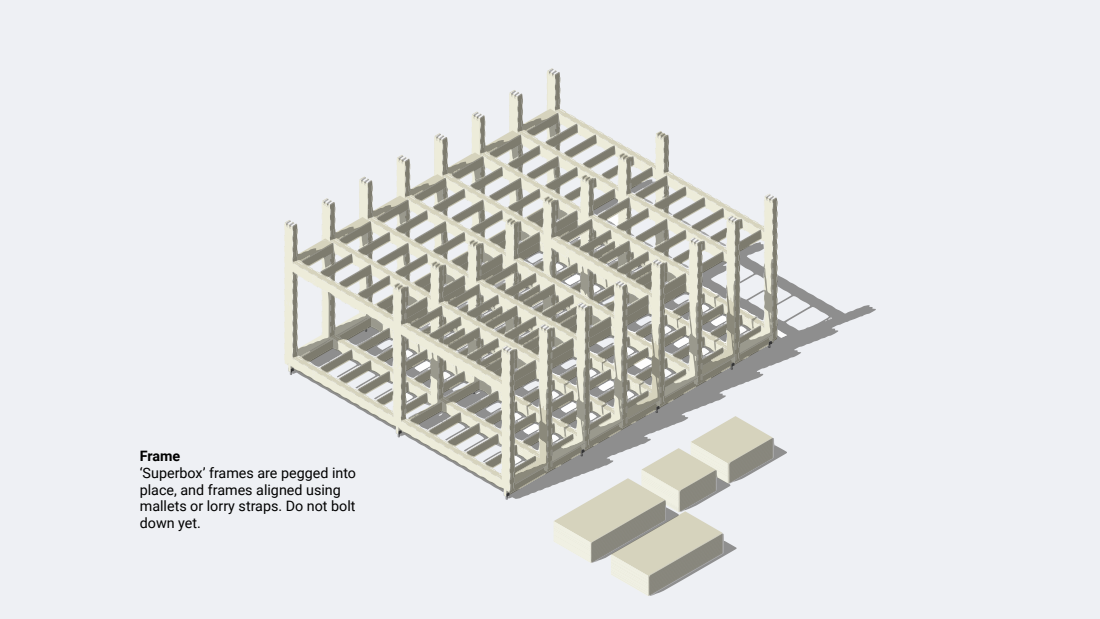
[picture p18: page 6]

Frame
‘Superbox’ frames are pegged into
place, and frames aligned using
mallets or lorry straps. Do not bolt
down yet.

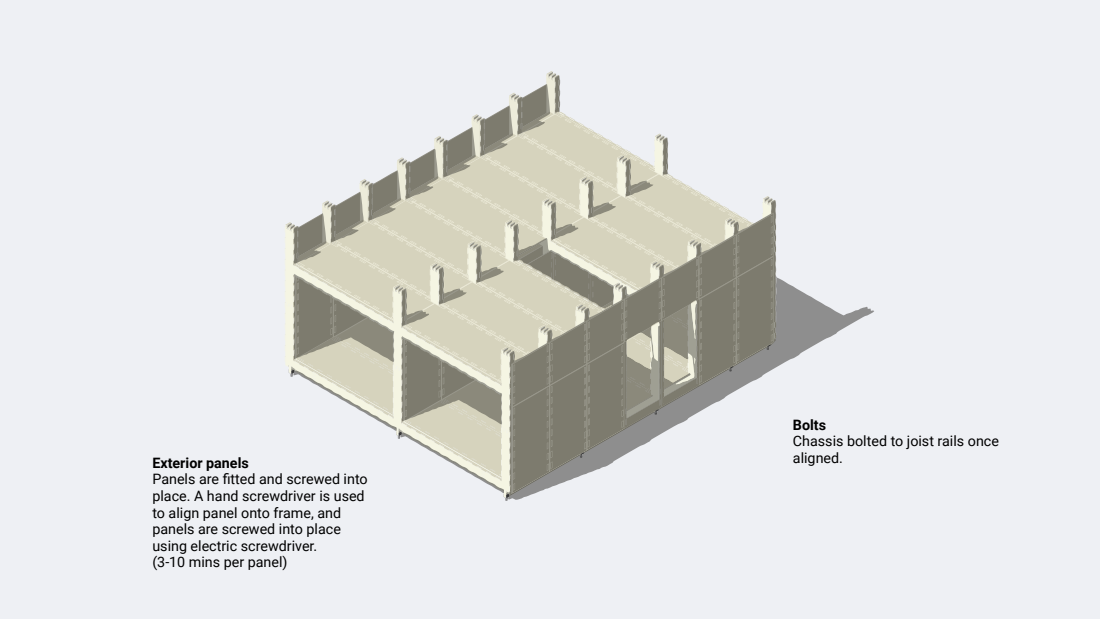
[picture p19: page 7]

Bolts
Chassis bolted to joist rails once
aligned.

Exterior panels
Panels are fitted and screwed into
place. A hand screwdriver is used
to align panel onto frame, and
panels are screwed into place
using electric screwdriver.
(3-10 mins per panel)

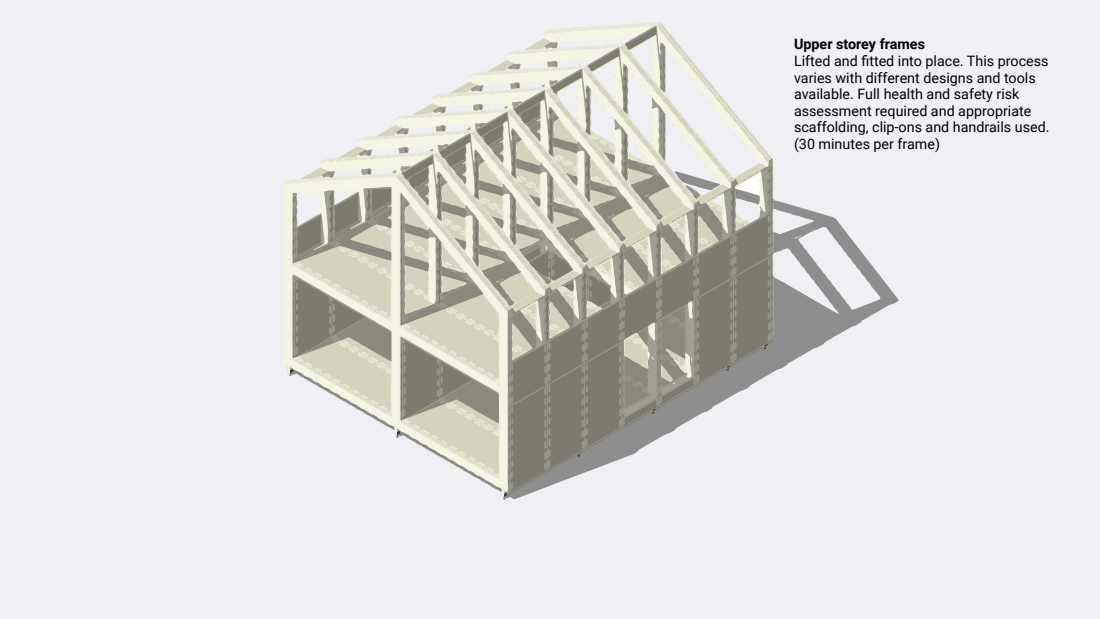
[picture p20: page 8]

Upper storey frames
Lifted and fitted into place. This process
varies with different designs and tools
available. Full health and safety risk
assessment required and appropriate
scaffolding, clip-ons and handrails used.
(30 minutes per frame)

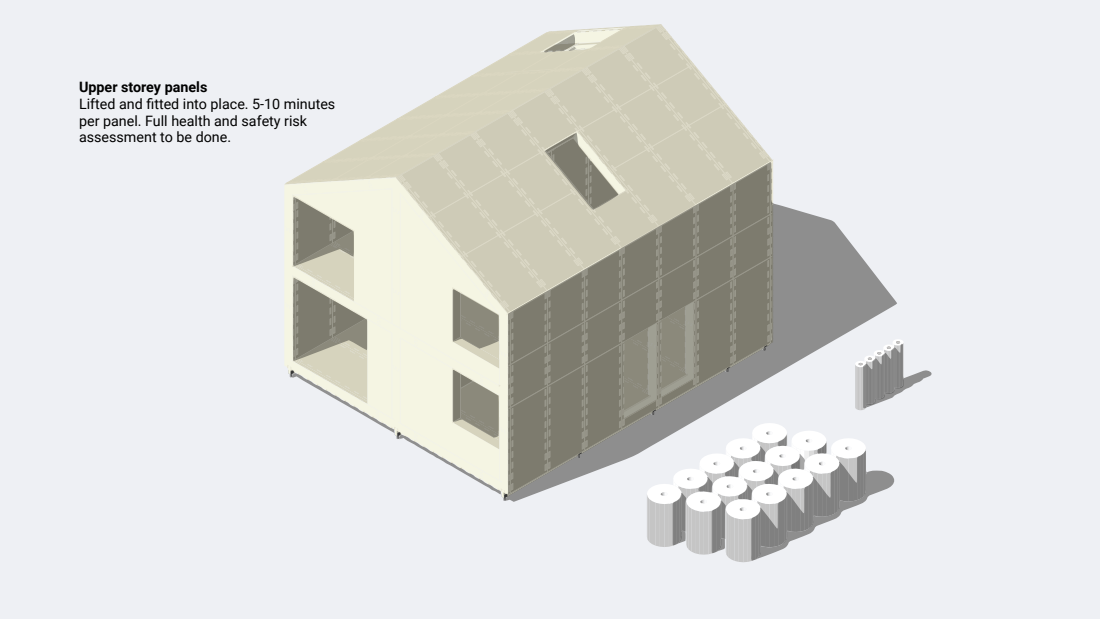
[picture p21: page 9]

Upper storey panels
Lifted and fitted into place. 5-10 minutes
per panel. Full health and safety risk
assessment to be done.

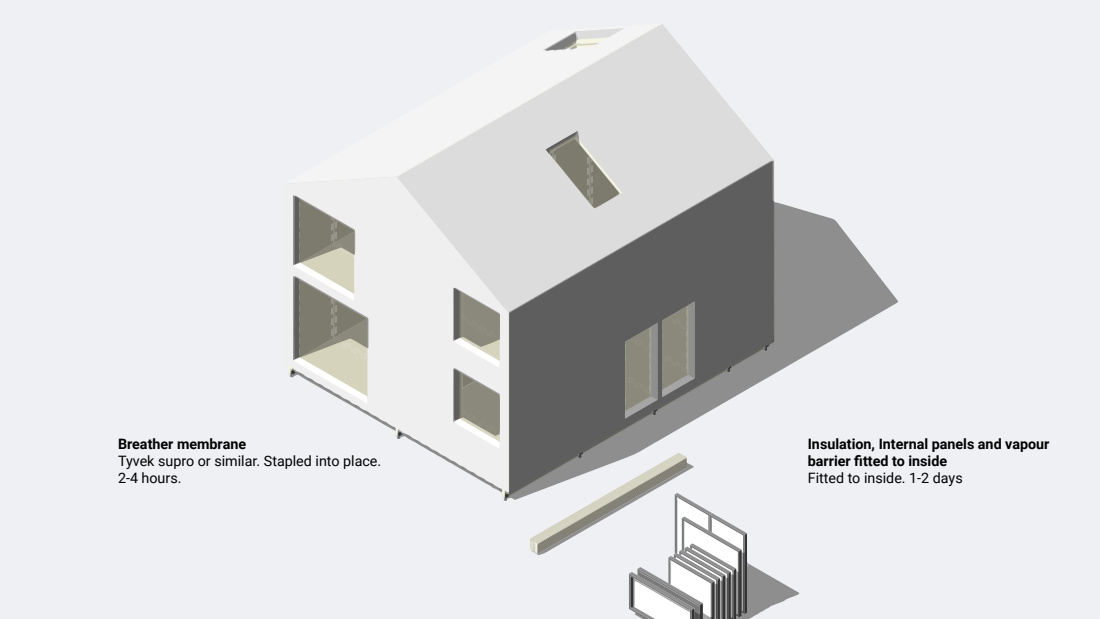
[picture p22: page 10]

Breather membrane
Tyvek supro or similar. Stapled into place.
2-4 hours.

Insulation, Internal panels and vapour
barrier fitted to inside
Fitted to inside. 1-2 days

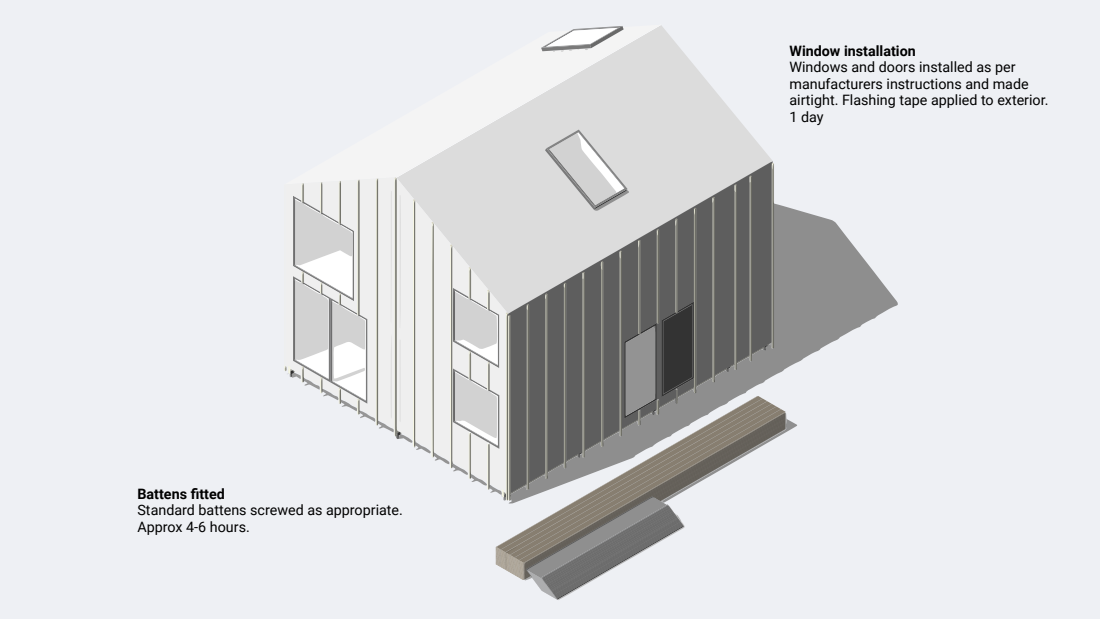
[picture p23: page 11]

Window installation
Windows and doors installed as per
manufacturers instructions and made
airtight. Flashing tape applied to exterior.
1 day

Battens fitted
Standard battens screwed as appropriate.
Approx 4-6 hours.

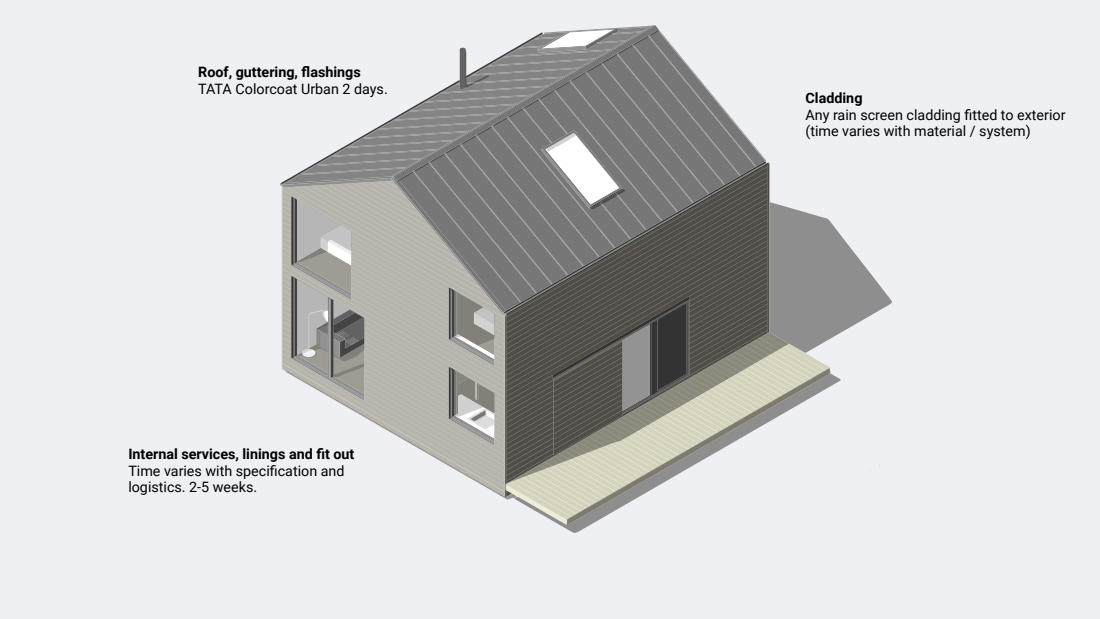
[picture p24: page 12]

Roof, guttering, flashings
TATA Colorcoat Urban 2 days.

Cladding
Any rain screen cladding fitted to exterior
(time varies with material / system)

Internal services, linings and fit out
Time varies with specification and
logistics. 2-5 weeks.

£

Affordable; Smart; Locally adaptable

Super low-energy

Customised form & layout

Interoperable components
based on open standards

Easy to maintain or
disassemble

Low-carbon / circular materials

Any foundation type

Open source / replicable


Insulation
Soft fill roll or full fill cellulose.

Spacers (or ’S’ pieces)
18mm structural plywood / OSB

Frames (or ‘F’ pieces)

Reinforcers (or ‘R’ pieces)


Insulation
Soft fill roll or full fill cellulose.

Superbox
18mm structural plywood / OSB

Peg

Connectors


External panels
18mm structural plywood / OSB


Insulation
Soft fill roll (eg Rockwool, sheep’s wool or
recycled plastic wool) 250mm depth

Breather Membrane
Tyvek Supro or similar


Internal panels
18mm structural plywood / OSB

Vapour barrier e.g Intello; Airtightness Tape e.g Tescon

Expanding foam
Small amount applied to superbox corner
compartment through delivery hole

Battens Usually 38mm x 38mm softwood

Services
As standard, including wiring, plumbing
and ventilation. ‘Plug and play’ where
possible.

Internal floor and ceiling panels
18mm structural plywood or OSB

Drywall; Skirting Timber, painted

Tapered edge, filled, painted Cladding
Any rainscreen cladding

Floor finishes
Any floor finish


WikiHouse Foundation | enquiries@wikihouse.cc
Unit 109b , 203-213 Mare Street London, UK UK non-profit 9152368 | www.wikihouse.cc
| @WikiHouse

v1.5 CC-BY-ND 01/2016

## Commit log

2016-12-20 Grasshopper parametric script for Wren v. 4.3
    A computational design script for creating a customisable Wren chassis in Grasshopper for Rhino 5
2016-12-20 Sample project engine for driving Grasshopper file
    Upload this into Google sheets to use in connection with the Wren Grasshopper script, using the Leafcutter plugin integrated with the Wren script.
    Alternatively switch out functions to run from Excel, using same cell addresses.
    Very helpful of controlling form and structural parameters, collating building data, and locating window/door openings.
    [My Project Engine.xlsx]
2017-08-08 The WREN assembly process and suggested build-up
    Some process and detail diagrams showing how WREN is typically constructed
